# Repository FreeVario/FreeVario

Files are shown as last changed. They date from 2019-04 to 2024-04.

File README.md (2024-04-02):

# FreeVario
Freevario is an opensource vario that provides telemetry data to any vario based program such as XCSoar or XCTrack via bluetooth or USB in the form of NMEA sentences. It's a custom build pcb board* featuring:
 <br>
  STM32F405 processor  <br>
  E-Ink display  <br>
  GNSS module <br>
  BMP280 presure sensor <br>
  mpu6050 motion sensor <br>
  HM13 bluetooth module <br>
  SX1276 Lora Modem (for FANET) <br>
  Micro SDcard reader <br>
  Piezo buzzer output <br>
  USB-C connector for OTG and charging <br>  
  SWDIO port
  Signal LED
  CN3055 LiPo charger  
<br>
*The board is development status and there are some errors, don't use it for production or anything

The firmware runs on FreeRtos and STM32 HAL drivers. 

A lot of firmware features still have to be added and developed, but the milestone releases are practically usable

<br>
<br>
<center>
  <p > 
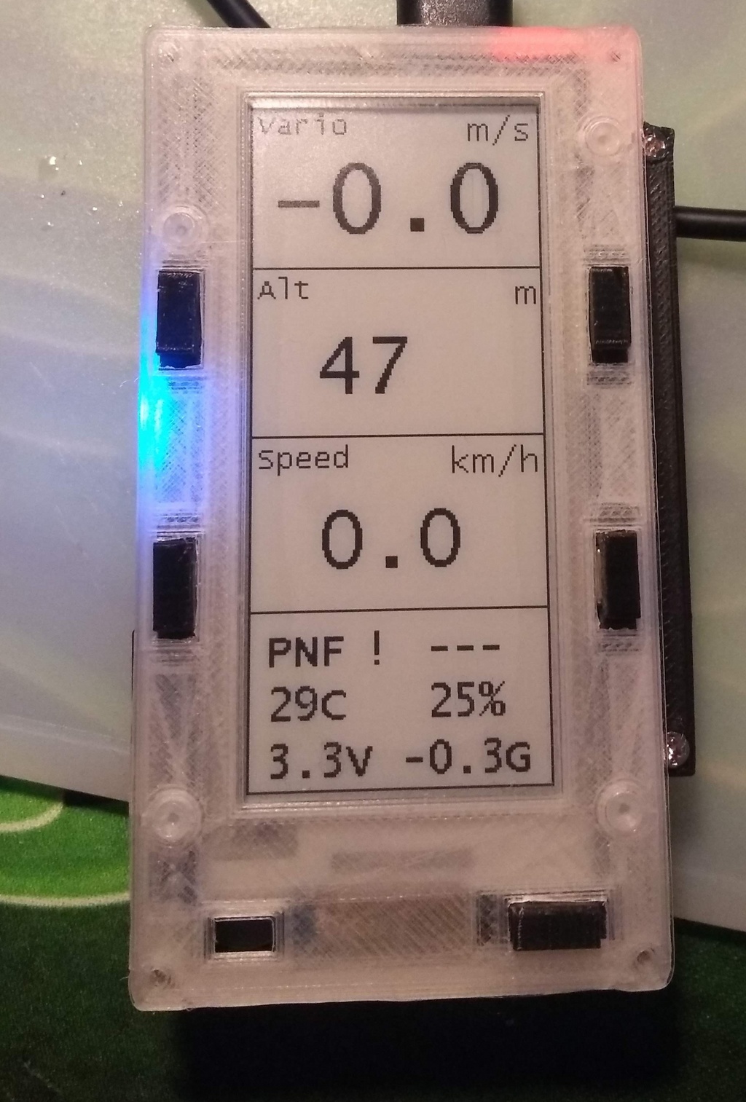
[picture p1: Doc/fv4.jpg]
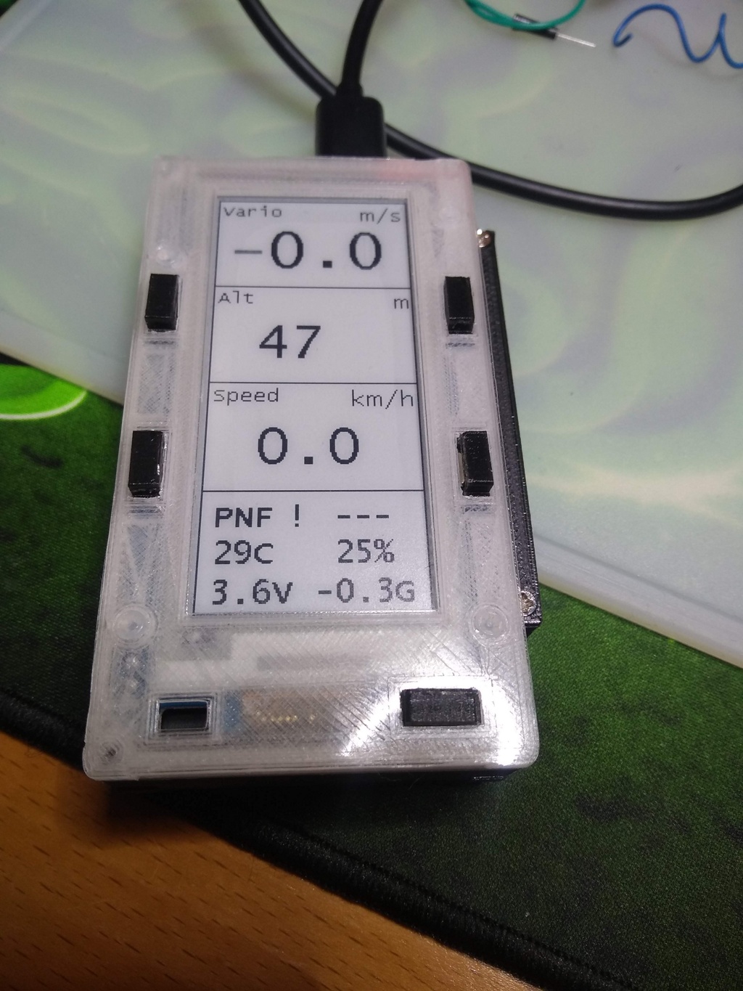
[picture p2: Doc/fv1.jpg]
     
  </p>
  
  <p > 
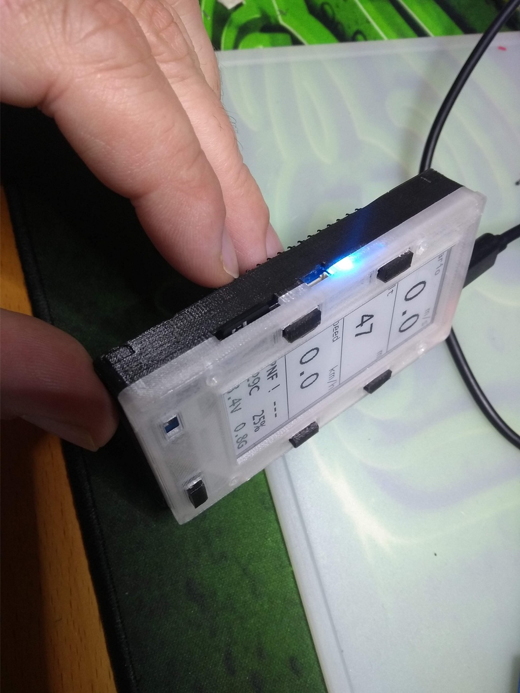
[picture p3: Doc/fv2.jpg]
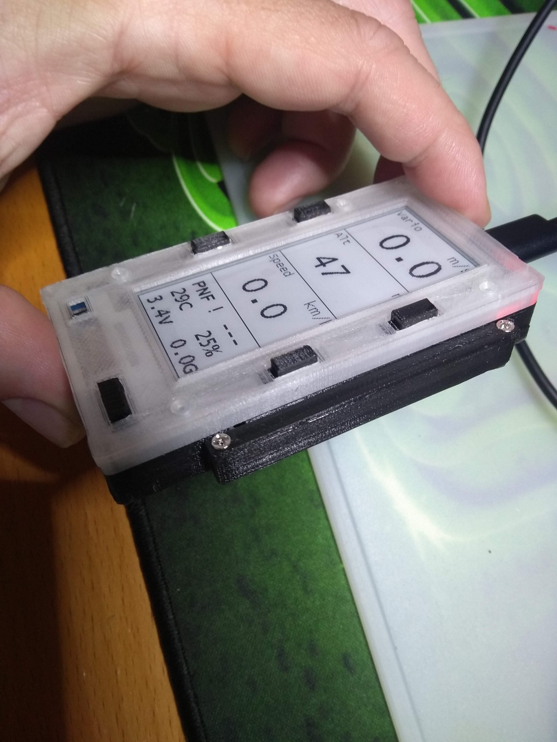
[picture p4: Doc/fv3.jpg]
     
  </p>
    <p > 
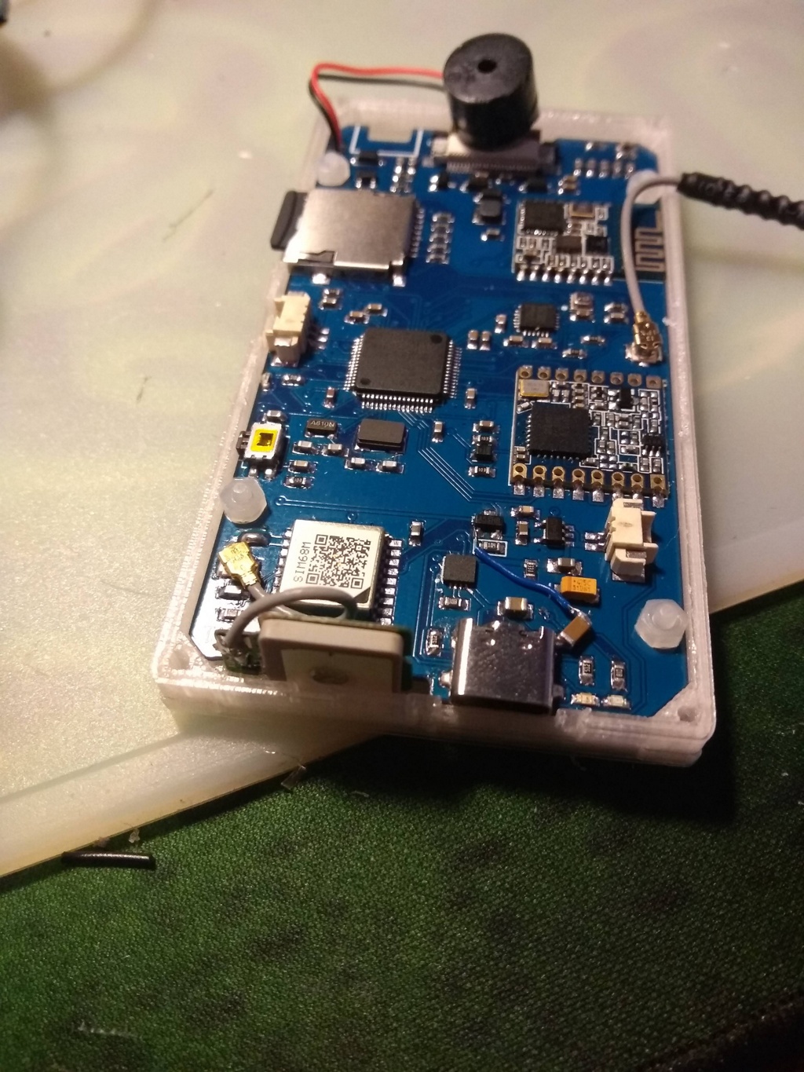
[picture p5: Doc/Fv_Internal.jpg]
    
  </p>
</center>

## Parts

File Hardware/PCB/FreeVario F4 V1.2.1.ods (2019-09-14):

Qty | Value | Device | Parts | Description
16 | 104 | C-EUC0603K | C3, C4, C22, C31, C32, C34, C35, C36, C37, C38, C39, C40, C41, C42, C43, C44 | CAPACITOR, European symbol
12 | 105 | C-EUC0603K | C2, C9, C10, C13, C15, C16, C19, C20, C23, C24, C25, C33 | CAPACITOR, European symbol
1 | 106 | C-EUC0603K | C12 | CAPACITOR, European symbol
1 | 223 | C-EUC0603K | C11 | CAPACITOR, European symbol
1 | 330 | R-EU_R0603 | R1 | RESISTOR, European symbol
1 | 0R | R-EU_R0603 | R9 | RESISTOR, European symbol
9 | 10k | R-EU_R0603 | R3, R6, R12, R13, R19, R21, R25, R26, R27 | RESISTOR, European symbol
1 | 10k | RES-0603 | R24
2 | 10p | C-EUC0603K | C5, C6 | CAPACITOR, European symbol
1 | 10R | R-EU_R0603 | R8 | RESISTOR, European symbol
1 | 10uF | C-EUC0603K | C21 | CAPACITOR, European symbol
1 | 10uF | C-EUC0805 | C18 | CAPACITOR, European symbol
2 | 1k | R-EU_R0603 | R7, R23 | RESISTOR, European symbol
1 | 1k | R-EU_R0603 | R2 | RESISTOR, European symbol
1 | 1N4148WS | DIODE-SOD323-R | D4 | DIODE
1 | 2.2nf | C-EUC0603K | C14 | CAPACITOR, European symbol
2 | 20p | C-EUC0603K | C7, C8 | CAPACITOR, European symbol
1 | 22uF | C-EUC0805 | C17 | CAPACITOR, European symbol
1 | 25MHZ | KX-9B | Y1 | Quartz Crystals (MHz) SMD:
1 | 27nH | INDUCTOR_0603_M | U$27 | Generic chip inductor
1 | 2k | R-EU_R0603 | R22 | RESISTOR, European symbol
1 | 2N7002 | MOSFET-NREFLOW | Q1 | N-Channel Mosfet
1 | 3R | R-EU_R0603 | R4 | RESISTOR, European symbol
1 | 4.7uF | 10UF-POLAR-EIA3216-16V-10%(TANT) | C1 | 10.0µF polarized capacitors
1 | 4.7uf | C-EUC0603K | C45 | CAPACITOR, European symbol
6 | 47k | R-EU_R0603 | R5, R11, R14, R15, R16, R20 | RESISTOR, European symbol
2 | 5.1k | R-EU_R0603 | R17, R18 | RESISTOR, European symbol
1 | 52745-2490 | 52745-2490 | X1 | FFC/FPC-to-Board 0.50mm (.020") SMT Top Contact
1 | 53261-02 | 53261-02 | BAT | CONNECTOR
1 | 53261-03 | 53261-03 | X3 | CONNECTOR
1 | 68uH | SWPA3015S2R2NT | L1 | Wire Wound SMD Power Inductor
1 | BME280 | BME280 | U1 | BME280 - Environmental Sensor (I2C + SPI)
1 | Cancel | MOMENTARY-SWITCH-SPST-SMD-6.0X3.5MM | S3 | Momentary Switch (Pushbutton) - SPST
1 | CN3065 | PMIC-CN3065-DFN8 | U3 | 310030101
1 | FC-135_32.7680KA-A0 | FC-135_32.7680KA-A0 | Y2 | None
1 | FDN340P | MOSFET-P'SI2323CDS/SI2305DS<BR>' | Q2 | 32.7680 Khz 20ppm 12.5pf
1 | GREEN | LEDCHIPLED_0603 | LED2 | LED
1 | HM-11 | HM-11 | HM13 | JNHuaMao HM-11 Bluetooth 4.0 Transceiver
4 | MBR0530 | DIODESOD-123 | D1, D2, D3, D5 | Diode
1 | MODULESX1276 | MODULESX1276 | U$4 | Module SX1276 LORA modem
1 | MPU-6050-1 | MPU-6050-1 | AC1
1 | Next | MOMENTARY-SWITCH-SPST-SMD-6.0X3.5MM | S4 | Momentary Switch (Pushbutton) - SPST
1 | OK | MOMENTARY-SWITCH-SPST-SMD-6.0X3.5MM | S5 | Momentary Switch (Pushbutton) - SPST
1 | Prev | MOMENTARY-SWITCH-SPST-SMD-6.0X3.5MM | S2 | Momentary Switch (Pushbutton) - SPST
1 | PWR | MOMENTARY-SWITCH-SPST-SMD-6.0X3.5MM | S1 | Momentary Switch (Pushbutton) - SPST
1 | RED | LEDCHIPLED_0603 | LED1 | LED
1 | RT9193-33 | MIC5219XX | REG1 | VOLTAGE REGULATOR
1 | s8050 | SMD-TRANSISTORS-PNP-25V-500MA(SOT-23) | T1 | 305020006
1 | SIM68M | SIM68M | U4
1 | STM32F405RGT6 | STM32F405RG | U$1 | STM32F405RGT6
1 | TF-HOLDER | TF-HOLDER | SD1 | TF / Micro SD socket is PUSH-PUSH type, the card can be pushed into and auto locked and pushed out by simply press the card.
2 | U.FL-R-SMT(01) | U.FL-R-SMT(01) | J1, J3 | U.FL Series 6 Ghz 50 Ohm Ultra-small SMT Coaxial Cable Receptacle
1 | USB-C_LOWSPEED | USB-C_LOWSPEED | U$2 | USB C Female connctor. Only uses the USB 2.0 data ports
1 |  | CONN_021X02_NO_SILK | J2 | Multi connection point. Often used as Generic Header-pin footprint for 0.1 inch spaced/style header connections
1 |  | LEDCHIP-LED0603 | LED3 | LED
1 |  | TS-015A | RESET | TS-15A

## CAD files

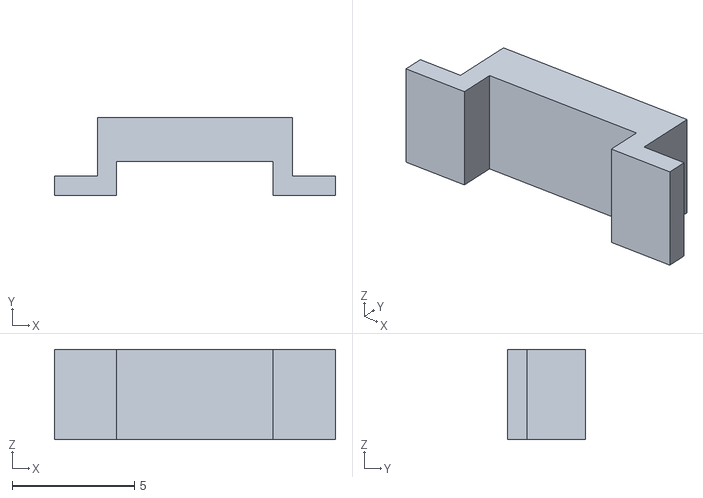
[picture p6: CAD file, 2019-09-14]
Hardware/Case/FreeVario F4 button.stl
11.5 x 3.20 x 3.70

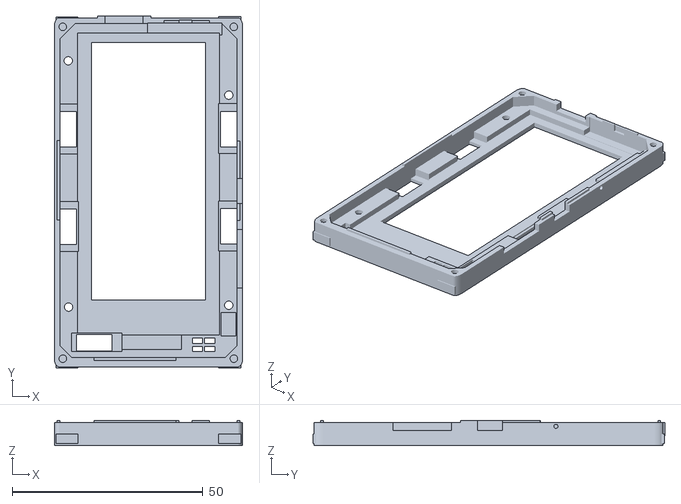
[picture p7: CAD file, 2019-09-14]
Hardware/Case/FreeVario F4 top.stl
49.4 x 92.3 x 6.60

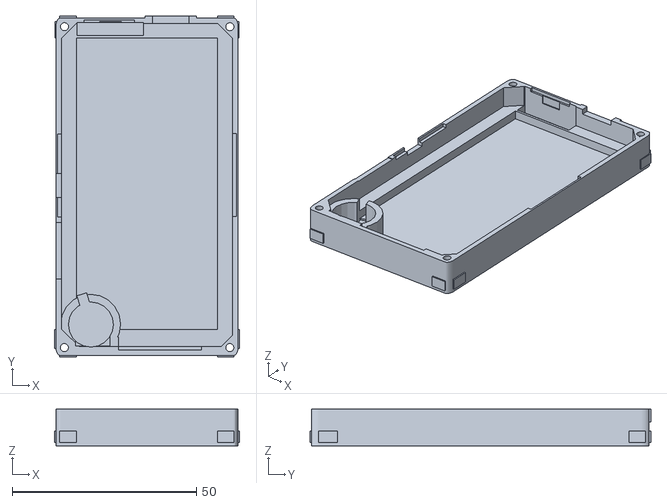
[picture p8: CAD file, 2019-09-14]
Hardware/Case/FreeVario F4 bottom.stl
50.2 x 92.5 x 10.0

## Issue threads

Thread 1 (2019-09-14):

Pcb design

Roeland54, 2019-09-14:
Hello,

I was in the starting phase of my own open source paragliding vario project with an e-paper display when I found your repository. It seems like the goals I had set for my project are more than fulfilled by yours.
I would love to make a FreeVario and maybe contribute to your project. I have the following questions:

- Can you add the pcb designs and maybe a bill of materials to the repository so I can start to build a FreeVario?
- Can you add The STL files for the 3d printed case to the repository.
- Do you plan on further developing the project?

primaldev, 2019-09-14:
Hi Roeland, thanks for your interest. I've added the files to the repository. You can use the eagle files if you need to modify the design, otherwise use the already prepared gerber files. All the parts is available from your nearest Chinese webshop (I kind of designed it for that).

At the moment it is still flying season so not much is done at the moment. I might pick it up again in the winter.

I had some bad luck with the pcb. I ordered a pcb with 1mm thickness and it turned out not being able to dissipate the heat of the charging chip properly and ended up tearing loose from the board. So advise at the moment is to use a thicker pcb.

Roeland54, 2020-02-22:
Hi, I finally picked this back up. Pcb and parts are ordered. Can you share the CAD files for the case? I may need to do some adjustments to the case to accommodate the thicker pcb. I also made the traces between the GND pad of the charging chip and the ground plane wider to improve thermal conductivity.

primaldev, 2020-02-22:
I sent you an email with a link to the project files on tinkercad.

thechillicherry, 2021-01-03:
Hey primaldev,
did you allready try the device? I found it like roeland54 i was looking for a vario which works with xctrack.
can you tell me where you ordered the components?
cheers thechillicherry

primaldev, 2021-01-03:
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

Hi, thanks for your interest, yes, I stil use it time to time, but have switched to another device (Mipfly). All the components should still be available from aliexpress. But keep in mind, this project requires a lot of skill and time and patience. This project had a smooth start, but I had a lot of last minute problems and just ran out of time for the season start and had to buy a commercial vario. You should be familiar with STM32 processors and coding, otherwise troubleshooting will be very difficult. Also, the LoRa should be left out. Turns out it was wired the wrong way around (Datasheet were incorrect/unclear).

A lot have changed the last few years with a lot of new players and projects on the market. Maybe, first have a look at [https://www.paraglidingforum.com/viewforum.php?f=39](url) for other options.

But if you are up for the challenge, I suggest contacting Roeland as well, he did some improvements on the PCB.

ra1amx, 2023-06-10:
Hi. You can add a BOM file and a component coordinate file to order a board on a production type jlcpcb.com
Thanks!

Closed 2024-07-13.

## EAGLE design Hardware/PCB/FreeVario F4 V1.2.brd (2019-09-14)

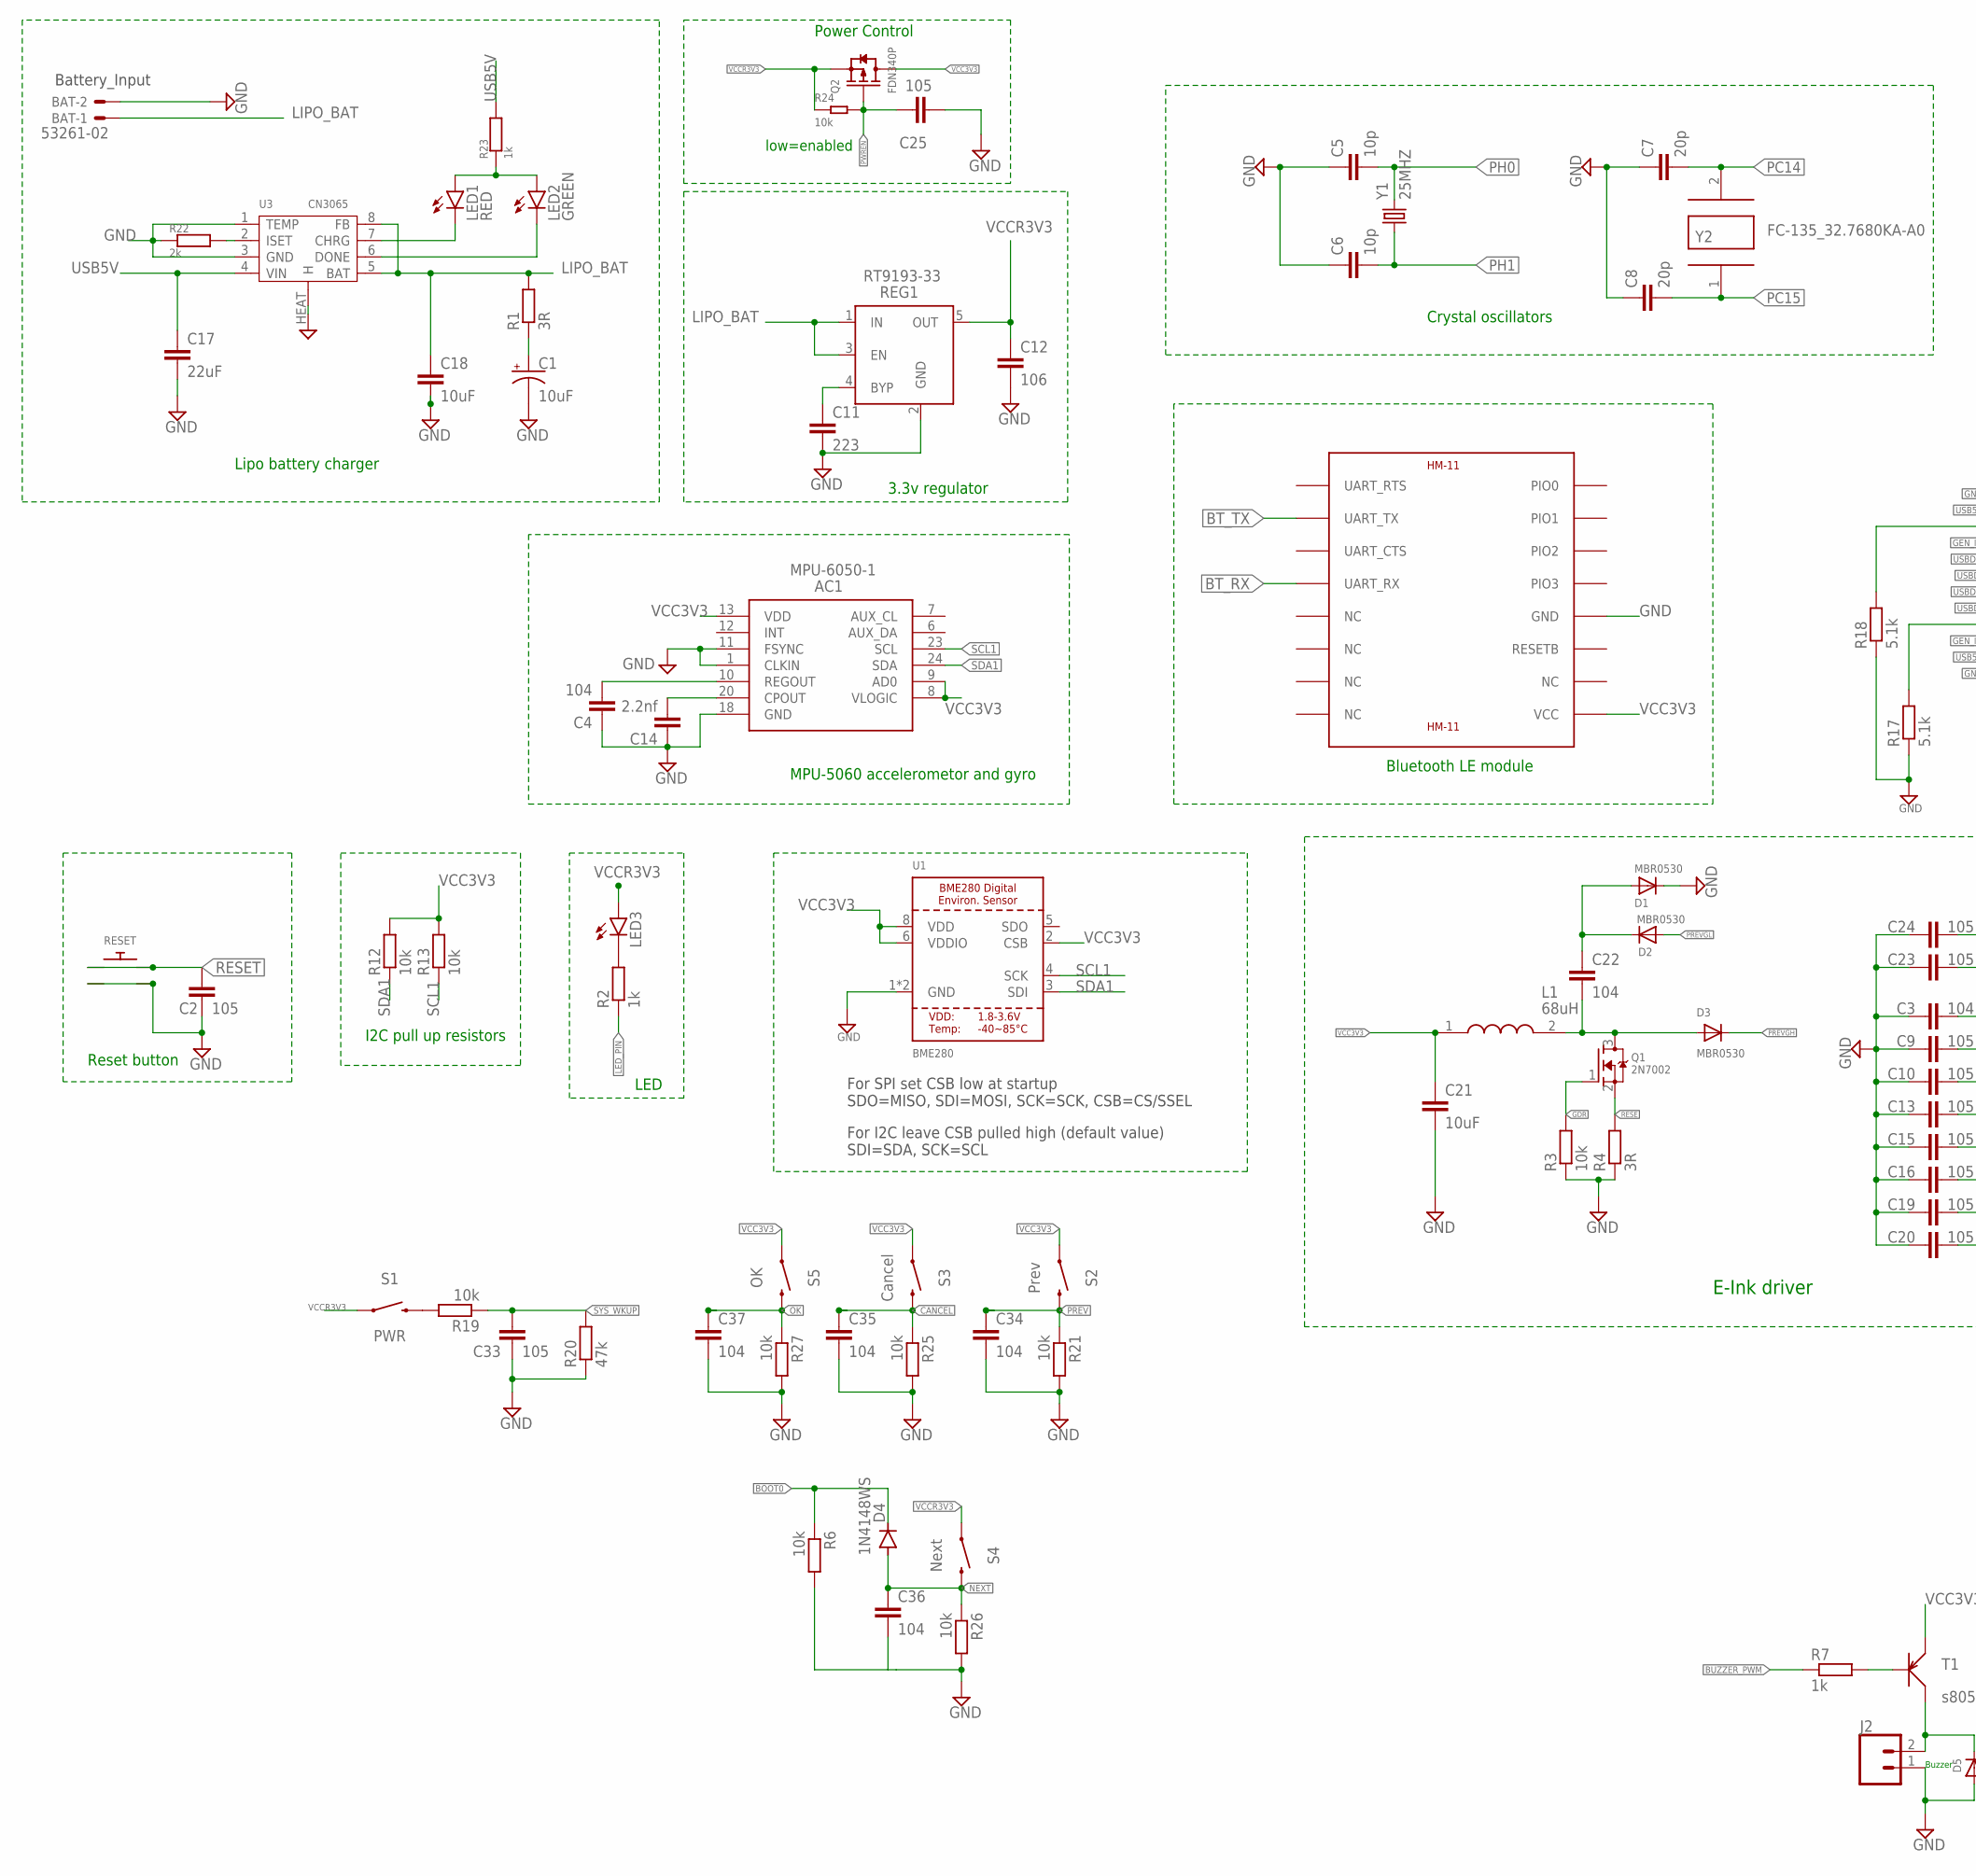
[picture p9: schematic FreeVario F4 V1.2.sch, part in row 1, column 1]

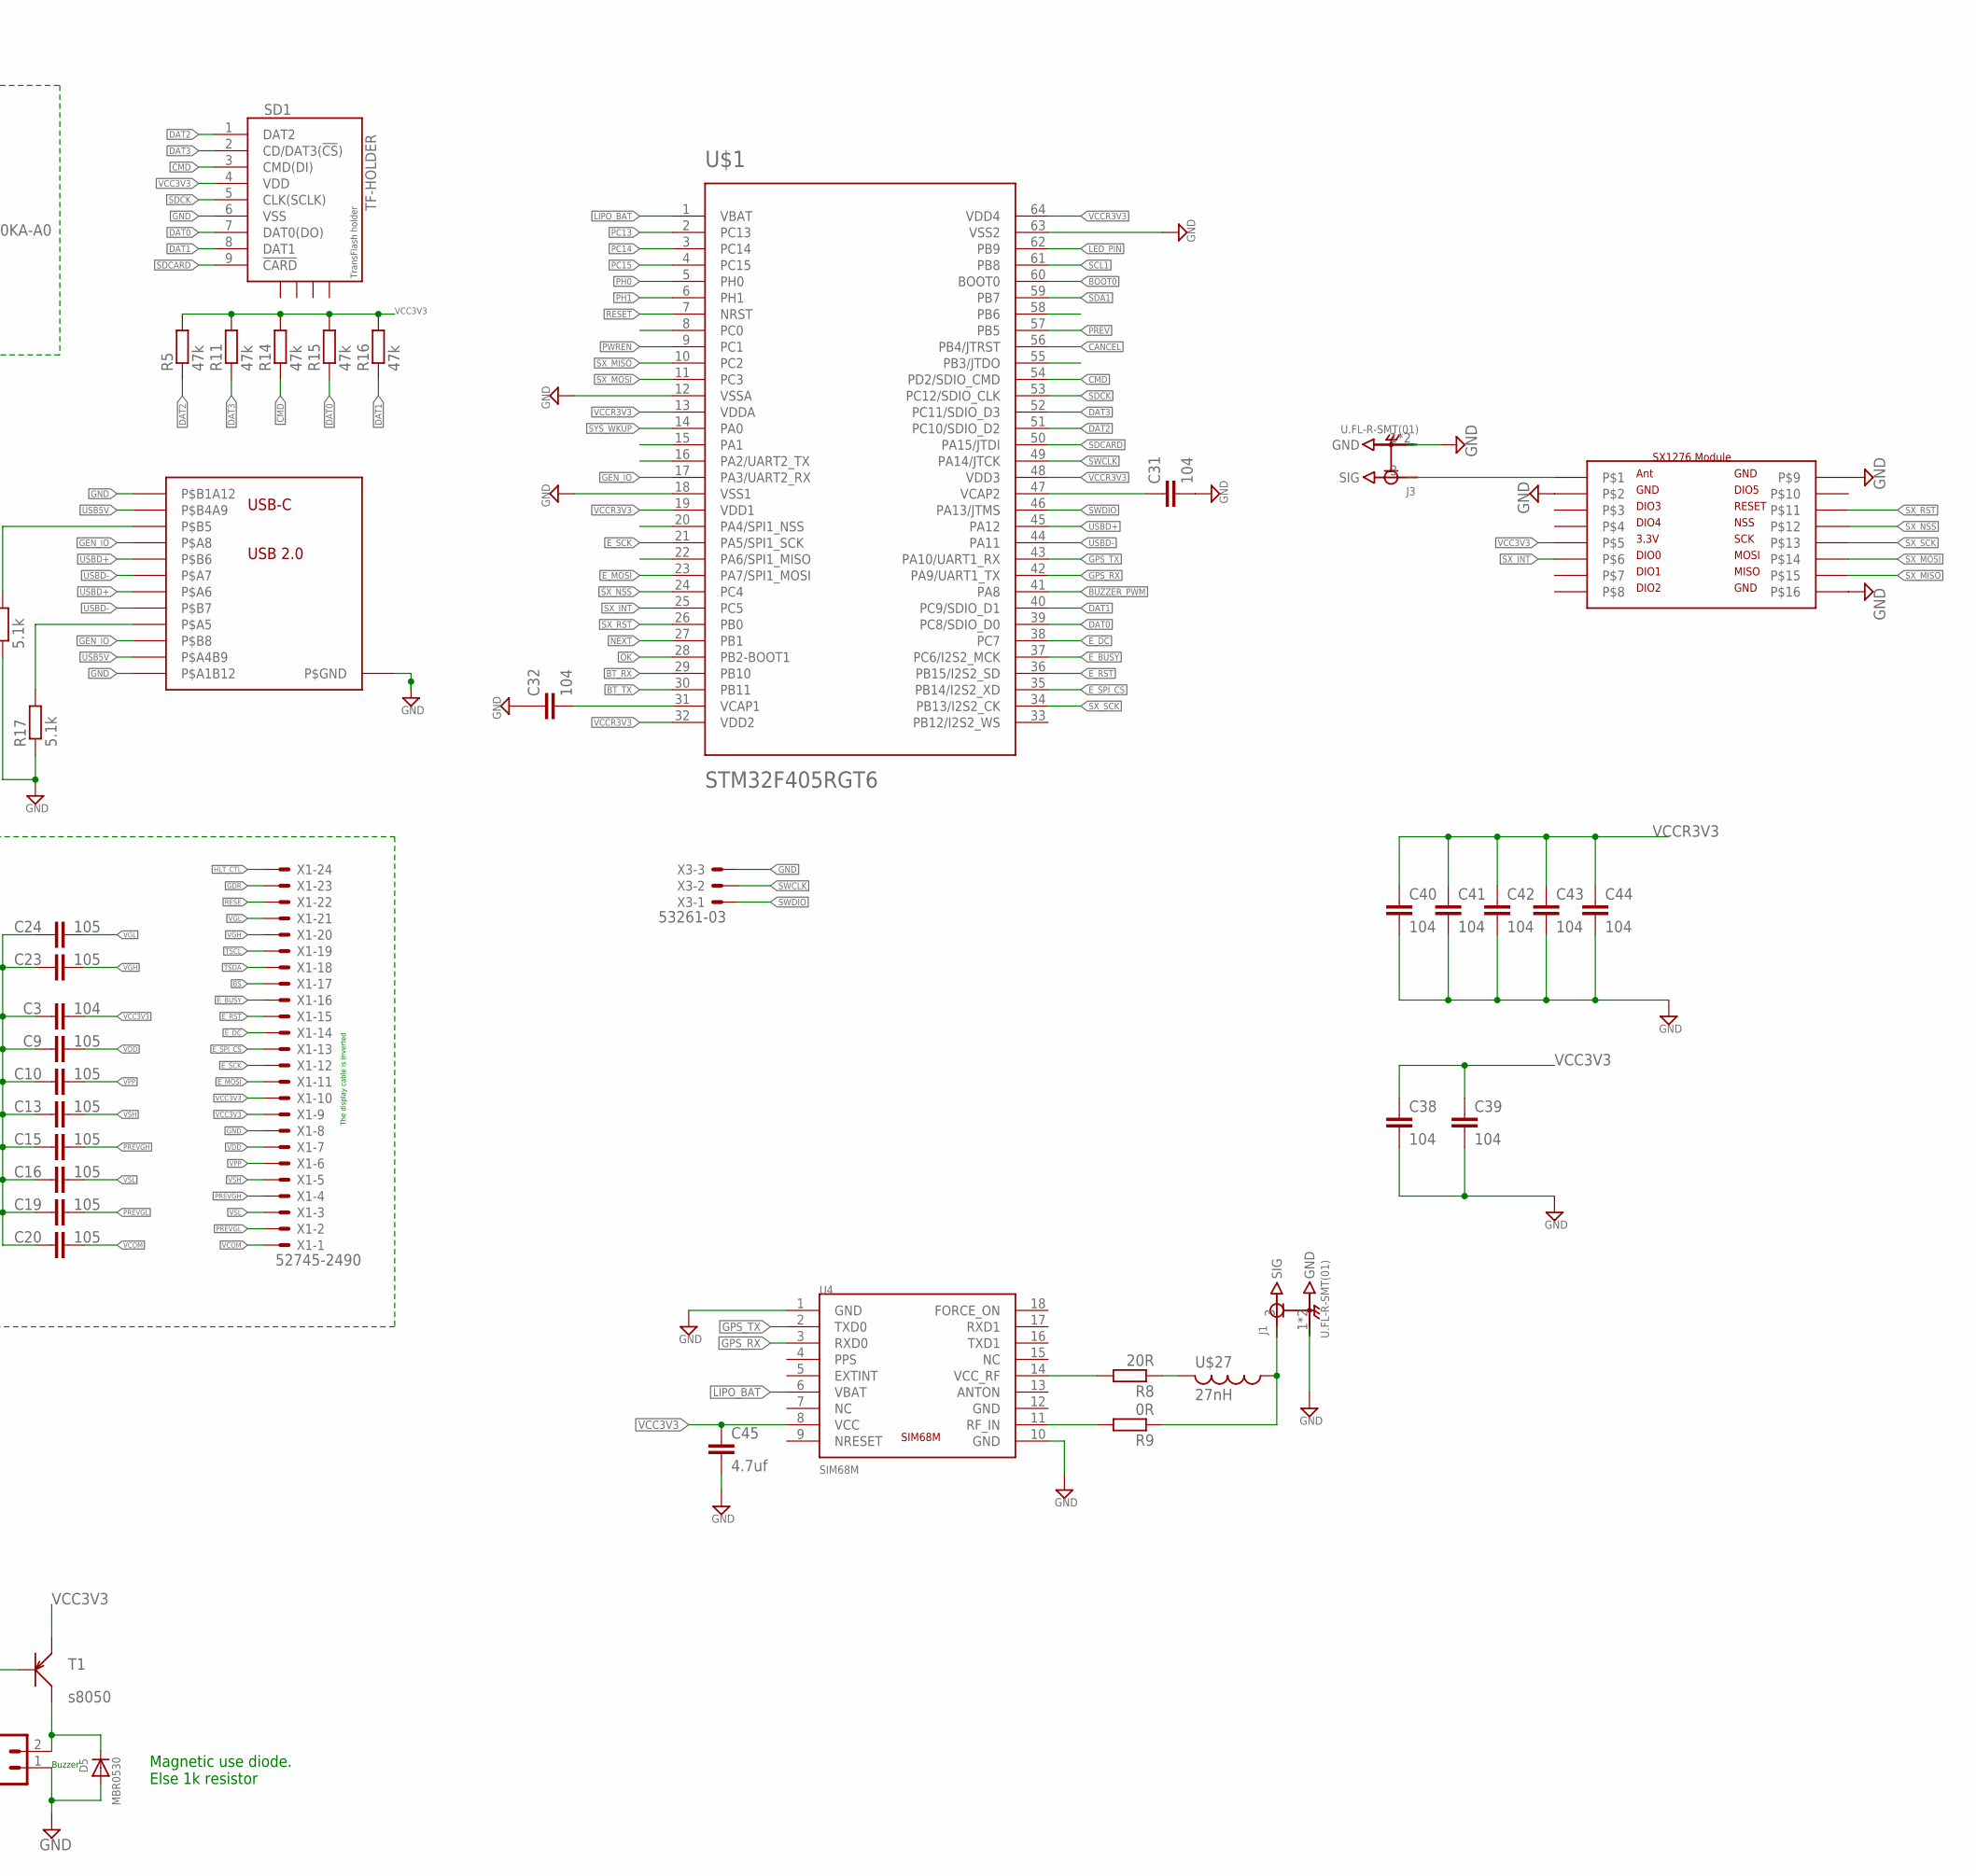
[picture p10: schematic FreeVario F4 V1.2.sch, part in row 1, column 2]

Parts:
AC1: MPU-6050-1; QFN-24-4MM2
BAT: 53261-02
C1: 10uF; EIA3216
C2, C9, C10, C13, C15, C16, C19, C20, C23, C24, C25, C33: 105; C0603K
C3, C4, C22, C31, C32, C34, C35, C36, C37, C38, C39, C40, C41, C42, C43, C44: 104; C0603K
C5, C6: 10p; C0603K
C7, C8: 20p; C0603K
C11: 223; C0603K
C12: 106; C0603K
C14: 2.2nf; C0603K
C17: 22uF; C0805
C18: 10uF; C0805
C21: 10uF; C0603K
C45: 4.7uf; C0603K
D1, D2, D3, D5: MBR0530; SOD-123
D4: 1N4148WS; SOD323-R
HM13: HM-11
J1, J3: U.FL-R-SMT(01); HRS_U.FL-R-SMT(01)
J2: CONN_021X02_NO_SILK; 1X02_NO_SILK
L1: 68uH; INDPM3030X150N
LED1: RED; CHIPLED_0603
LED2: GREEN; CHIPLED_0603
LED3: LEDCHIP-LED0603; CHIP-LED0603
Q1: 2N7002; SOT23
Q2: FDN340P; SOT-23
R1, R4: 3R; R0603
R2, R7, R23: 1k; R0603
R3, R6, R12, R13, R19, R21, R24, R25, R26, R27: 10k; R0603
R5, R11, R14, R15, R16, R20: 47k; R0603
R8: 20R; R0603
R9: 0R; R0603
R17, R18: 5.1k; R0603
R22: 2k; R0603
REG1: RT9193-33; SOT23-5
RESET: TS-015A
S1: PWR; TACTILE_SWITCH_SMD_6.0X3.5MM
S2: Prev; TACTILE_SWITCH_SMD_6.0X3.5MM
S3: Cancel; TACTILE_SWITCH_SMD_6.0X3.5MM
S4: Next; TACTILE_SWITCH_SMD_6.0X3.5MM
S5: OK; TACTILE_SWITCH_SMD_6.0X3.5MM
SD1: TF-HOLDER; TF-PULL
T1: s8050; SOT-23
U1: BME280
U3: CN3065; DFN-8
U4: SIM68M
U$1: STM32F405RGT6; TQFP64
U$2: USB-C_LOWSPEED
U$4: MODULESX1276
U$27: 27nH; RESC0603_M
X1: 52745-2490
X3: 53261-03
Y1: 25MHZ; 5.0X3.2_2
Y2: FC-135_32.7680KA-A0; XTAL_FC-135_32.7680KA-A0

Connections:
BOOT0: D4.C, R6.1, U$1.60 (BOOT0)
BS: X1.17
BT_RX: HM13.UART_RX, U$1.29 (PB10)
BT_TX: HM13.UART_TX, U$1.30 (PB11)
BUZZER_PWM: R7.1, U$1.41 (PA8)
CANCEL: C35.1, R25.1, S3.2, U$1.56 (PB4/JTRST)
CMD: R14.1, SD1.3 (CMD(DI)), U$1.54 (PD2/SDIO_CMD)
DAT0: R15.1, SD1.7 (DAT0(DO)), U$1.39 (PC8/SDIO_D0)
DAT1: R16.1, SD1.8 (DAT1), U$1.40 (PC9/SDIO_D1)
DAT2: R5.1, SD1.1 (DAT2), U$1.51 (PC10/SDIO_D2)
DAT3: R11.1, SD1.2 (CD/DAT3(!CS!)), U$1.52 (PC11/SDIO_D3)
E_BUSY: U$1.37 (PC6/I2S2_MCK), X1.16
E_DC: U$1.38 (PC7), X1.14
E_MOSI: U$1.23 (PA7/SPI1_MOSI), X1.11
E_RST: U$1.36 (PB15/I2S2_SD), X1.15
E_SCK: U$1.21 (PA5/SPI1_SCK), X1.12
E_SPI_CS: U$1.35 (PB14/I2S2_XD), X1.13
GDR: Q1.1 (G), R3.2, X1.23
GEN_IO: U$1.17 (PA3/UART2_RX), U$2.P$A8, U$2.P$B8
GND: AC1.1 (CLKIN), AC1.11 (FSYNC), AC1.18 (GND), BAT.2, C1.-, C2.2, C3.1, C4.1, C5.1, C6.1, C7.1, C8.1, C9.1, C10.1, C11.2, C12.2, C13.1, C14.1, C15.1, C16.1, C17.2, C18.2, C19.1, C20.1, C21.2, C23.1, C24.1, C25.2, C31.2, C32.1, C33.2, C34.2, C35.2, C36.2, C37.2, C38.2, C39.2, C40.2, C41.2, C42.2, C43.2, C44.2, C45.2, D1.C, D5.A, HM13.GND, J1.1 (GND), J1.2 (GND), J2.1, J3.1 (GND), J3.2 (GND), R3.1, R4.1, R6.2, R17.1, R18.1, R20.1, R21.2, R22.1, R25.2, R26.2, R27.2, REG1.2 (GND), RESET.P$2, RESET.P$4, SD1.6 (VSS), U1.1 (GND), U1.7 (GND), U3.1 (TEMP), U3.3 (GND), U3.HEAT (H), U4.1 (GND), U4.10 (GND), U4.12 (GND), U$1.12 (VSSA), U$1.18 (VSS1), U$1.63 (VSS2), U$2.P$1 (P$GND), U$2.P$2 (P$GND), U$2.P$20 (P$GND), U$2.P$21 (P$GND), U$2.P$22 (P$GND), U$2.P$23 (P$GND), U$2.P$A1B12, U$2.P$B1A12, U$4.SX2, U$4.SX9, U$4.SX16, X1.8, X3.3
GPS_RX: U4.3 (RXD0), U$1.42 (PA9/UART1_TX)
GPS_TX: U4.2 (TXD0), U$1.43 (PA10/UART1_RX)
HLT_CTL: X1.24
LED_PIN: R2.1, U$1.62 (PB9)
LIPO_BAT: BAT.1, C18.1, R1.2, REG1.1 (IN), REG1.3 (EN), U3.5 (BAT), U3.8 (FB), U4.6 (VBAT), U$1.1 (VBAT)
unnamed: LED1.A, LED2.A, R23.1
unnamed: LED1.C, U3.7 (CHRG)
unnamed: LED2.C, U3.6 (DONE)
unnamed: C1.+, R1.1
unnamed: C11.1, REG1.4 (BYP)
unnamed: J1.3 (SIG), R9.1, U$27.1
unnamed: LED3.C, R2.2
unnamed: C22.2, D3.A, L1.2, Q1.3 (D)
unnamed: R19.2, S1.2
unnamed: R8.1, U$27.2
unnamed: C22.1, D1.A, D2.C
unnamed: J3.3 (SIG), U$4.SX1
unnamed: D5.C, J2.2, T1.3 (C)
unnamed: R7.2, T1.1 (B)
unnamed: AC1.10 (REGOUT), C4.2
unnamed: R8.2, U4.14 (VCC_RF)
unnamed: R22.2, U3.2 (ISET)
unnamed: AC1.20 (CPOUT), C14.2
unnamed: R9.2, U4.11 (RF_IN)
unnamed: C32.2, U$1.31 (VCAP1)
unnamed: C31.1, U$1.47 (VCAP2)
unnamed: R17.2, U$2.P$A5
unnamed: R18.2, U$2.P$B5
NEXT: C36.1, D4.A, R26.1, S4.2, U$1.27 (PB1)
OK: C37.1, R27.1, S5.2, U$1.28 (PB2-BOOT1)
PC0: U$1.8 (PC0)
PC13: U$1.2 (PC13)
PC14: C7.2, U$1.3 (PC14), Y2.2
PC15: C8.2, U$1.4 (PC15), Y2.1
PH0: C5.2, U$1.5 (PH0), Y1.2
PH1: C6.2, U$1.6 (PH1), Y1.1
PREV: C34.1, R21.1, S2.2, U$1.57 (PB5)
PREVGH: C15.2, D3.C, X1.4
PREVGL: C19.2, D2.A, X1.2
PWREN: C25.1, Q2.1 (G), R24.2, U$1.9 (PC1)
RESE: Q1.2 (S), R4.2, X1.22
RESET: C2.1, RESET.P$1, RESET.P$3, U$1.7 (NRST)
SCL1: AC1.23 (SCL), R13.1, U1.4 (SCK), U$1.61 (PB8)
SDA1: AC1.24 (SDA), R12.1, U1.3 (SDI), U$1.59 (PB7)
SDCARD: SD1.9 (!CARD), U$1.50 (PA15/JTDI)
SDCK: SD1.5 (CLK(SCLK)), U$1.53 (PC12/SDIO_CLK)
SWCLK: U$1.49 (PA14/JTCK), X3.2
SWDIO: U$1.46 (PA13/JTMS), X3.1
SX_INT: U$1.25 (PC5), U$4.SX6
SX_MISO: U$1.10 (PC2), U$4.SX15
SX_MOSI: U$1.11 (PC3), U$4.SX14
SX_NSS: U$1.24 (PC4), U$4.SX12
SX_RST: U$1.26 (PB0), U$4.SX11
SX_SCK: U$1.34 (PB13/I2S2_CK), U$4.SX13
SYS_WKUP: C33.1, R19.1, R20.2, U$1.14 (PA0)
TSCL: X1.19
TSDA: X1.18
USB5V: C17.1, R23.2, U3.4 (VIN), U$2.P$A4B9, U$2.P$B4A9
USBD+: U$1.45 (PA12), U$2.P$A6, U$2.P$B6
USBD-: U$1.44 (PA11), U$2.P$A7, U$2.P$B7
VCC3V3: AC1.8 (VLOGIC), AC1.9 (AD0), AC1.13 (VDD), C3.2, C21.1, C38.1, C39.1, C45.1, HM13.VCC, L1.1, Q2.3 (D), R5.2, R11.2, R12.2, R13.2, R14.2, R15.2, R16.2, S2.1, S3.1, S5.1, SD1.4 (VDD), T1.2 (E), U1.2 (CSB), U1.6 (VDDIO), U1.8 (VDD), U4.8 (VCC), U$4.SX5, X1.9, X1.10
VCCR3V3: C12.1, C40.1, C41.1, C42.1, C43.1, C44.1, LED3.A, Q2.2 (S), R24.1, REG1.5 (OUT), S1.1, S4.1, U$1.13 (VDDA), U$1.19 (VDD1), U$1.32 (VDD2), U$1.48 (VDD3), U$1.64 (VDD4)
VCOM: C20.2, X1.1
VDD: C9.2, X1.7
VGH: C23.2, X1.20
VGL: C24.2, X1.21
VPP: C10.2, X1.6
VSH: C13.2, X1.5
VSL: C16.2, X1.3

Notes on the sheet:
Battery_Input
Lipo battery charger
Bluetooth LE module
MPU-5060 accelerometor and gyro
3.3v regulator
Reset button
I2C pull up resistors
LED
For SPI set CSB low at startup SDO=MISO, SDI=MOSI, SCK=SCK, CSB=CS/SSEL
For I2C leave CSB pulled high (default value) SDI=SDA, SCK=SCL
Crystal oscillators
The display cable is inverted
Power Control
low=enabled
E-Ink driver
Buzzer
Magnetic use diode. Else 1k resistor

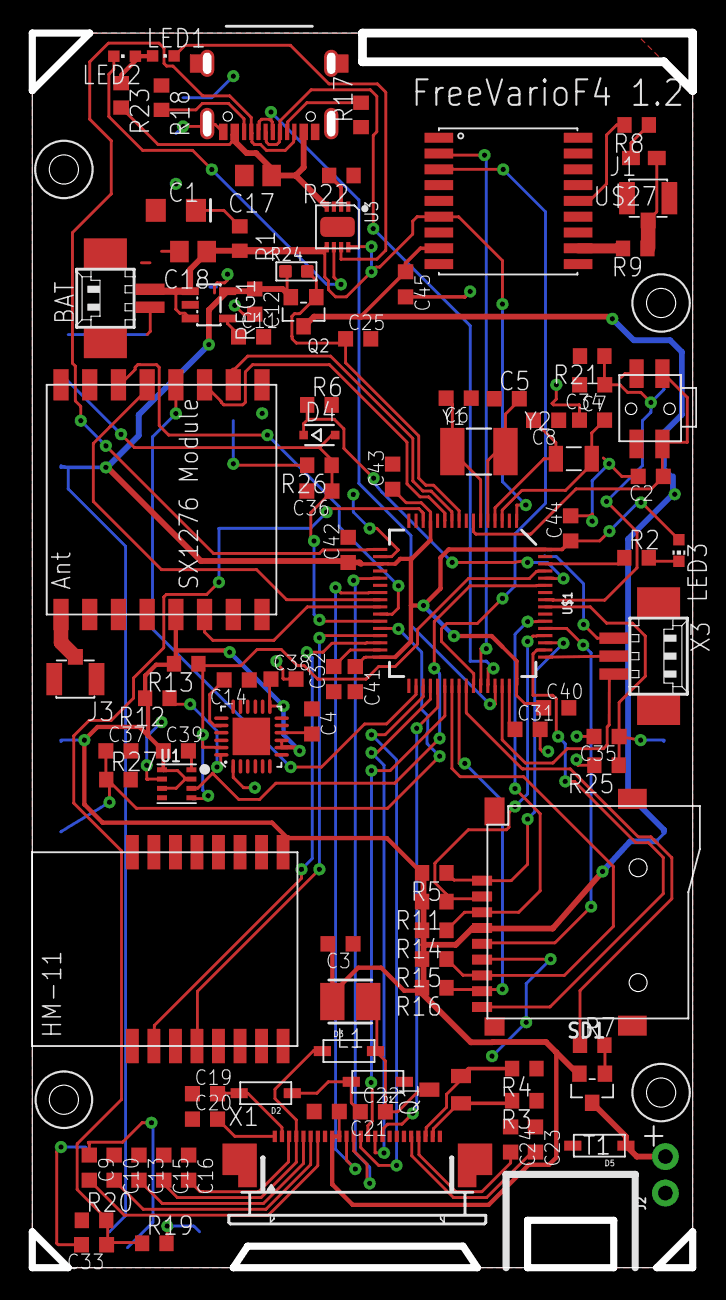
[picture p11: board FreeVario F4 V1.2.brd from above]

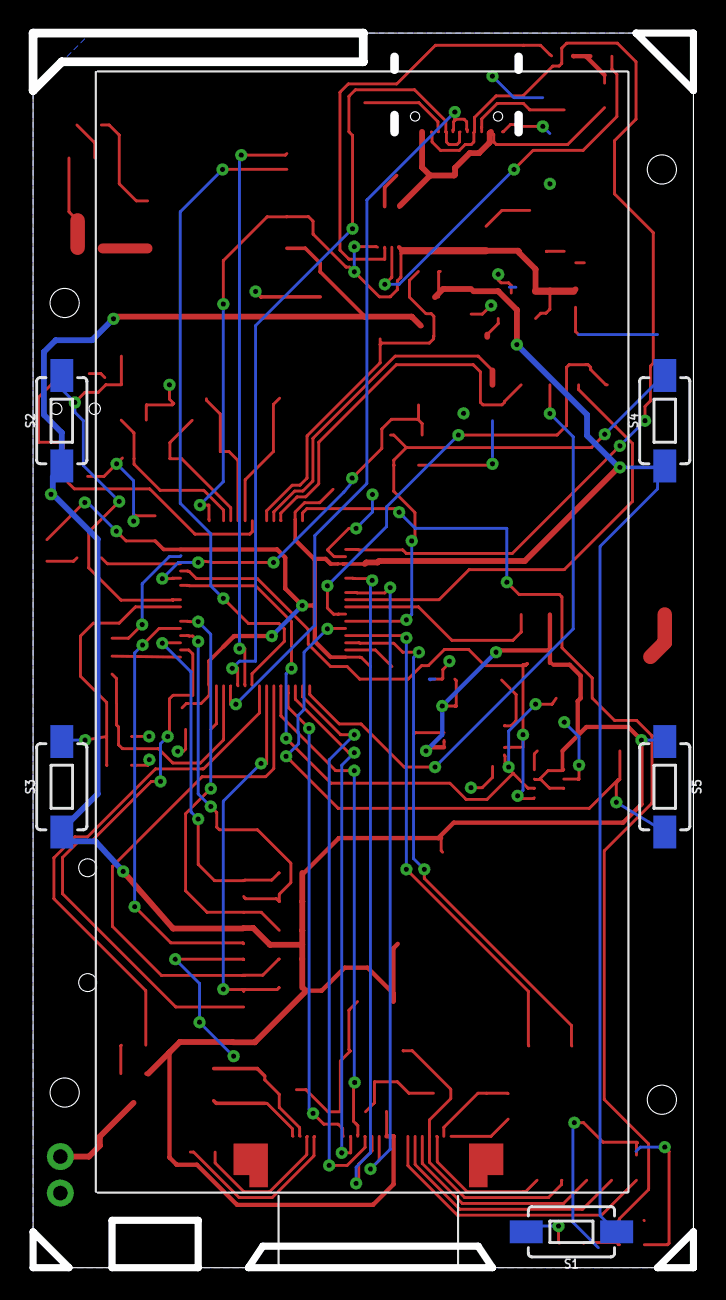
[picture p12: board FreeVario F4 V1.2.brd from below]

Board: 2 copper layers, 46.0 x 86.0 mm, 103 parts (5 on the bottom side), 83 nets.

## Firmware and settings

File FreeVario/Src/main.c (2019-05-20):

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

/* Includes ------------------------------------------------------------------*/
#include "main.h"
#include "cmsis_os.h"
#include "fatfs.h"
#include "usb_device.h"

/* USER CODE BEGIN Includes */
#include "freevario.h"
/* USER CODE END Includes */

ADC_HandleTypeDef hadc1;

I2C_HandleTypeDef hi2c1;

RTC_HandleTypeDef hrtc;

SD_HandleTypeDef hsd;
DMA_HandleTypeDef hdma_sdio_rx;
DMA_HandleTypeDef hdma_sdio_tx;

SPI_HandleTypeDef hspi1;
SPI_HandleTypeDef hspi2;

TIM_HandleTypeDef htim1;

UART_HandleTypeDef huart1;
UART_HandleTypeDef huart3;
DMA_HandleTypeDef hdma_usart1_rx;
DMA_HandleTypeDef hdma_usart3_tx;

WWDG_HandleTypeDef hwwdg;

osThreadId defaultTaskHandle;
/* USER CODE BEGIN PV */


/* USER CODE END PV */

void SystemClock_Config(void);
static void MX_GPIO_Init(void);
static void MX_DMA_Init(void);
static void MX_USART3_UART_Init(void);
static void MX_SPI1_Init(void);
static void MX_SPI2_Init(void);
static void MX_I2C1_Init(void);
static void MX_SDIO_SD_Init(void);
static void MX_USART1_UART_Init(void);
static void MX_TIM1_Init(void);
static void MX_RTC_Init(void);
static void MX_ADC1_Init(void);
static void MX_WWDG_Init(void);
void StartDefaultTask(void const * argument);

/* USER CODE BEGIN PFP */

/* USER CODE END PFP */

/**
  * @brief  The application entry point.
  * @retval int
  */
int main(void)
{
  /* MCU Configuration--------------------------------------------------------*/

  /* Reset of all peripherals, Initializes the Flash interface and the Systick. */
  HAL_Init();

  /* Configure the system clock */
  SystemClock_Config();

  /* USER CODE BEGIN SysInit */
//After using generate code in cubeMX, add this after GPIO_INIT :   HAL_Delay(100);


  MX_GPIO_Init();
  HAL_Delay(100);
  MX_DMA_Init();
  MX_USART3_UART_Init();
  MX_SPI1_Init();
  MX_SPI2_Init();
  MX_I2C1_Init();
  MX_SDIO_SD_Init();
  MX_USART1_UART_Init();
  MX_TIM1_Init();
  MX_RTC_Init();
  MX_ADC1_Init();


  /* USER CODE END SysInit */

  /* Initialize all configured peripherals */
  /* USER CODE BEGIN 2 */
#ifndef  DEBUG_MODE
  /*Disable RTC tamper*/

  HAL_RTCEx_DeactivateTamper(&hrtc, RTC_TAMPER_1);
  __HAL_RTC_TAMPER_CLEAR_FLAG(&hrtc, RTC_FLAG_TAMP1F);
  __HAL_RTC_WRITEPROTECTION_DISABLE(&hrtc);
  HAL_PWR_EnableBkUpAccess();

 /*
  * Bug fix for pwr button
  * Button must be held in for 3 seconds to powerup
  */

    uint32_t extRequest = HAL_RTCEx_BKUPRead(&hrtc, 0);

    /*check if the shutdown was proper */
    /*if not, continue startup in case of a wwdg reset*/
    if (extRequest == 3) { //had normal shutdown
        HAL_Delay(PWRBUTTONDELAY);
        if (HAL_GPIO_ReadPin(PWRBUTTON_GPIO_Port, PWRBUTTON_Pin)
                == GPIO_PIN_RESET) {
            StandbyMode();
        }

        /*Clear the proper shutdown flag */
        HAL_RTCEx_BKUPWrite(&hrtc, 0, 1); //do normal startup

    } else {
        HAL_RTCEx_BKUPWrite(&hrtc, 0, 2); //unexpected restart
    }

#endif

#ifndef  DEBUG_MODE
  MX_WWDG_Init();
#endif


//Support for previous model that uses NPN transistor for the buzzer
  //TODO: read cpu serial as a switch



#ifdef FV_NPN_CHECK


  if ((STM32_UUID[2]) == 825503794) { //Id of the 1 board that needs this

        //char buff[30];
        //sprintf(buff, "serial %d \r\n", idPart3);
        //CDC_Transmit_FS(buff, 30);

        TIM_OC_InitTypeDef sConfigOC = { 0 };
        sConfigOC.OCMode = TIM_OCMODE_PWM1;
        sConfigOC.Pulse = 0;
        sConfigOC.OCPolarity = TIM_OCPOLARITY_LOW;
        sConfigOC.OCNPolarity = TIM_OCNPOLARITY_LOW;
        sConfigOC.OCFastMode = TIM_OCFAST_DISABLE;
        sConfigOC.OCIdleState = TIM_OCIDLESTATE_RESET;
        sConfigOC.OCNIdleState = TIM_OCNIDLESTATE_RESET;
        if (HAL_TIM_PWM_ConfigChannel(&htim1, &sConfigOC, TIM_CHANNEL_1)
                != HAL_OK) {
            Error_Handler();
        }

    }

#endif
  /* USER CODE END 2 */

  /* USER CODE BEGIN RTOS_MUTEX */
  /* add mutexes, ... */
  /* USER CODE END RTOS_MUTEX */

  /* USER CODE BEGIN RTOS_SEMAPHORES */
  /* add semaphores, ... */
  /* USER CODE END RTOS_SEMAPHORES */

  /* USER CODE BEGIN RTOS_TIMERS */
  /* start timers, add new ones, ... */
  /* USER CODE END RTOS_TIMERS */

  /* Create the thread(s) */
  /* definition and creation of defaultTask */
  osThreadDef(defaultTask, StartDefaultTask, osPriorityNormal, 0, 1024);
  defaultTaskHandle = osThreadCreate(osThread(defaultTask), NULL);

  /* USER CODE BEGIN RTOS_THREADS */
  /* add threads, ... */

  freeVario_RTOS_Init();



  /* USER CODE END RTOS_THREADS */

  /* USER CODE BEGIN RTOS_QUEUES */
  /* add queues, ... */
  /* USER CODE END RTOS_QUEUES */
 

  /* Start scheduler */
  osKernelStart();
  
  /* We should never get here as control is now taken by the scheduler */

  /* Infinite loop */
  /* USER CODE BEGIN WHILE */
  while (1)
  {

    /* USER CODE END WHILE */

    /* USER CODE BEGIN 3 */

  }
  /* USER CODE END 3 */
}

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
/* USER CODE BEGIN Header_StartDefaultTask */
/**
  * @brief  Function implementing the defaultTask thread.
  * @param  argument: Not used 
  * @retval None
  */
/* USER CODE END Header_StartDefaultTask */
__weak void StartDefaultTask(void const * argument)
{

  /* USER CODE BEGIN 5 */
  /* Infinite loop */
  for(;;)
  {

    osDelay(1);
  }
  /* USER CODE END 5 */ 
}

/**
  * @brief  Period elapsed callback in non blocking mode
  * @note   This function is called  when TIM5 interrupt took place, inside
  * HAL_TIM_IRQHandler(). It makes a direct call to HAL_IncTick() to increment
  * a global variable "uwTick" used as application time base.
  * @param  htim : TIM handle
  * @retval None
  */
void HAL_TIM_PeriodElapsedCallback(TIM_HandleTypeDef *htim)
{
  if (htim->Instance == TIM5) {
    HAL_IncTick();
  }
}

/**
  * @brief  This function is executed in case of error occurrence.
  * @retval None
  */
void Error_Handler(void)
{
  /* USER CODE BEGIN Error_Handler_Debug */
  /* User can add his own implementation to report the HAL error return state */
  while(1)
  {
  }
  /* USER CODE END Error_Handler_Debug */
}

#ifdef  USE_FULL_ASSERT
/**
  * @brief  Reports the name of the source file and the source line number
  *         where the assert_param error has occurred.
  * @param  file: pointer to the source file name
  * @param  line: assert_param error line source number
  * @retval None
  */
void assert_failed(uint8_t *file, uint32_t line)
{ 
  /* USER CODE BEGIN 6 */
  /* User can add his own implementation to report the file name and line number,
     tex: printf("Wrong parameters value: file %s on line %d\r\n", file, line) */
  /* USER CODE END 6 */
}
#endif /* USE_FULL_ASSERT */

/************************ (C) COPYRIGHT STMicroelectronics *****END OF FILE****/

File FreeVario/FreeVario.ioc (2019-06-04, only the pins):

Mcu.UserName=STM32F405RGTx
PA0-WKUP.GPIO_Label=PWRBUTTON
PA0-WKUP.Signal=GPXTI0
PA10.GPIO_Label=GPS_USART_RX
PA10.Signal=USART1_RX
PA11.Signal=USB_OTG_FS_DM
PA12.Signal=USB_OTG_FS_DP
PA13.Signal=SYS_JTMS-SWDIO
PA14.Signal=SYS_JTCK-SWCLK
PA15.GPIO_Label=SDCARD
PA15.Signal=GPIO_Input
PA5.Signal=SPI1_SCK
PA7.Signal=SPI1_MOSI
PA8.GPIO_Label=BUZZER_PWM
PA8.Signal=S_TIM1_CH1
PA9.GPIO_Label=GPS_USART_TX
PA9.Signal=USART1_TX
PB0.GPIO_Label=SX_RST
PB0.Signal=GPIO_Output
PB1.GPIO_Label=BTN_NEXT
PB1.Signal=GPXTI1
PB10.GPIO_Label=BT_USART_TX
PB10.Signal=USART3_TX
PB11.GPIO_Label=BT_USART_RX
PB11.Signal=USART3_RX
PB13.Signal=SPI2_SCK
PB14.GPIO_Label=SPI_CS
PB14.Signal=GPIO_Output
PB15.GPIO_Label=RST
PB15.Signal=GPIO_Output
PB2.GPIO_Label=BTN_OK
PB2.Signal=GPXTI2
PB4.GPIO_Label=BTN_CANCEL
PB4.Signal=GPXTI4
PB5.GPIO_Label=BTN_PREV
PB5.Signal=GPXTI5
PB7.Signal=I2C1_SDA
PB8.Signal=I2C1_SCL
PB9.GPIO_Label=LED
PB9.Signal=GPIO_Output
PC1.GPIO_Label=PWR_EN
PC1.Signal=GPIO_Output
PC10.Signal=SDIO_D2
PC11.Signal=SDIO_D3
PC12.Signal=SDIO_CK
PC14-OSC32_IN.Signal=RCC_OSC32_IN
PC15-OSC32_OUT.Signal=RCC_OSC32_OUT
PC2.Signal=SPI2_MISO
PC3.Signal=SPI2_MOSI
PC4.GPIO_Label=SX_NSS
PC4.Signal=GPIO_Output
PC5.GPIO_Label=SX_INT
PC5.Signal=GPIO_Input
PC6.GPIO_Label=BUSY
PC6.Signal=GPIO_Input
PC7.GPIO_Label=DC
PC7.Signal=GPIO_Output
PC8.Signal=SDIO_D0
PC9.Signal=SDIO_D1
PD2.Signal=SDIO_CMD
PH0-OSC_IN.Signal=RCC_OSC_IN
PH1-OSC_OUT.Signal=RCC_OSC_OUT

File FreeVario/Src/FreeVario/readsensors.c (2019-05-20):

/*
 FreeVario http://FreeVario.org

 Copyright (c), FreeVario (http://freevario.org)
 This program is free software: you can redistribute it and/or modify
 it under the terms of the GNU General Public License as published by
 the Free Software Foundation, either version 3 of the License, or
 any later version. see <http://www.gnu.org/licenses/>
 */

#include "readsensors.h"
#include "kalman.h"
#include "MadgwickAHRS.h"
#include "freevario.h"

extern I2C_HandleTypeDef FV_I2C;
extern ADC_HandleTypeDef FV_HALADC;


#define MPU6050_ACCE_SENS_2         ((float) 16384)
#define MPU6050_ACCE_SENS_4         ((float) 8192)
#define MPU6050_ACCE_SENS_8         ((float) 4096)
#define MPU6050_ACCE_SENS_16        ((float) 2048)

#define QUAT_W 0
#define QUAT_X 1
#define QUAT_Y 2
#define QUAT_Z 3

#define VEC_X 0
#define VEC_Y 1
#define VEC_Z 2

char _orientation[9] = { 0, -1, 0, 1, 0, 0, 0, 0, -1 };

static uint8_t vTriggerd;
static uint32_t vtime = 0;

void setupVbatSensor() {
    HAL_ADC_Start(&FV_HALADC);
    sensors.vbat = 30;
    sensors.pbat = 100;

}

void readVbatSensor() {

    if (HAL_ADC_PollForConversion(&FV_HALADC, 100) == HAL_OK) {

        uint32_t cnv = HAL_ADC_GetValue(&FV_HALADC);

        /*TODO: in dire need of calibration, use your scope man*/
        sensors.vbat = (sensors.vbat * 10 + (float)((cnv * 2 * 62) / 0xfff) )
                / 11; //lowpassfilter

        //calculate %charge, sort of
        sensors.pbat = (uint8_t) ((37 - sensors.vbat) * 16.6);

        if (sensors.pbat > 100) {
            sensors.pbat = 100;
        }

    }

}

void setupReadSensorsBMP280(BMP280_HandleTypedef *bmp280) {
    //TODO: Replace with official drivers
    //https://github.com/BoschSensortec/BME280_driver

    bmp280_init_default_params(&bmp280->params);
    bmp280->addr = BMP280_I2C_ADDRESS_0;
    bmp280->i2c = &FV_I2C;

    bmp280->params.mode = BMP280_MODE_NORMAL;
    bmp280->params.filter = BMP280_FILTER_2;
    bmp280->params.oversampling_pressure = BMP280_ULTRA_HIGH_RES;
    bmp280->params.oversampling_temperature = BMP280_LOW_POWER;
    bmp280->params.oversampling_humidity = BMP280_ULTRA_LOW_POWER;
    bmp280->params.standby = BMP280_STANDBY_05;

    while (!bmp280_init(bmp280, &bmp280->params)) {
    }

    SO_setQueue(&sensors.QAltitudeMeters, 10); //vario m/s

}

void setupReadSensorsMPU6050(SD_MPU6050 *mpu1) {
    SD_MPU6050_Init(&FV_I2C, mpu1, FV_ACCL_ADR, SD_MPU6050_Accelerometer_4G,
            SD_MPU6050_Gyroscope_250s);

    SD_MPU6050_SetOrientation(&FV_I2C, mpu1, Matrix2Scalar(_orientation));
}

void setupKalman() {

    KalmanFilter_Configure(Z_VARIANCE, ZACCEL_VARIANCE, ZACCELBIAS_VARIANCE, 0,
            0.0f, 0.0f);

}

//not yet used, needs work
void calcSensorsKalman(BMP280_HandleTypedef *bmp280, SD_MPU6050 *mpu1) {
    float zTrack, vTrack;

    sensors.accel_x = mpu1->Accelerometer_X * 100 / MPU6050_ACCE_SENS_4;
    sensors.accel_y = 0; //mpu1->Accelerometer_Y*100/MPU6050_ACCE_SENS_4;
    sensors.accel_z = (mpu1->Accelerometer_Z * 100 / MPU6050_ACCE_SENS_4) - 98; //upside down

    sensors.gyro_x = (ACCLSMOOTH * sensors.gyro_x + mpu1->Gyroscope_X)
            / (ACCLSMOOTH + 1);
    sensors.gyro_y = (ACCLSMOOTH * sensors.gyro_y + mpu1->Gyroscope_Y)
            / (ACCLSMOOTH + 1);
    sensors.gyro_z = (ACCLSMOOTH * sensors.gyro_z + mpu1->Gyroscope_Z)
            / (ACCLSMOOTH + 1);

    // MadgwickAHRSupdateIMU(sensors.gyro_x,sensors.gyro_y, sensors.gyro_z,sensors.accel_x,sensors.accel_y, sensors.accel_z);

    //float accelv = (9.8f*imu_GravityCompensatedAccel(sensors.accel_x,sensors.accel_y, sensors.accel_z));

    float accelv = 9.8f
            * sqrtf(powf(sensors.accel_x, 2) + powf(sensors.accel_z, 2)); //just the z and x axes

    sensors.gforce = accelv / 100;

    if (activity.useKalman) {
        KalmanFilter_Update((float) sensors.VarioMsRaw / 10, accelv / 100,
                (float) SENSORREADMS / 1000, &zTrack, &vTrack); // values must be cm/s
        sensors.VarioMs = vTrack * 10; //from cm/s to mm/s
    } else {
        sensors.VarioMs = sensors.VarioMsRaw;
    }

}

void readSensorsBMP280(BMP280_HandleTypedef *bmp280) {

    uint32_t pressure;
    int16_t temperature, humidity;

    while (!bmp280_read_int(bmp280, &temperature, &pressure, &humidity)) {

    }

    sensors.humidity = humidity;
    sensors.temperature = temperature;
    sensors.pressureraw = pressure;

    if (activity.useKalman) {
        sensors.pressure = pressure;
    } else {
        sensors.pressure = (sensors.variosmooth * sensors.pressure + pressure)
                / (sensors.variosmooth + 1);

    }

}

void readSensorsMPU6050(SD_MPU6050 *mpu1) {

    SD_MPU6050_ReadAll(&FV_I2C, mpu1);

}

float getAltitudeFeet() { //x1000

    return getAltitudeMeters() * 145366.45;

}

float getAltitudeMeters() {

    return 44330.0f
            * (1.0f
                    - powf(
                            ((float) sensors.pressure / 100)
                                    / (float) conf.qnePressure, 0.1902949f)); //because Pressure is in Pa x 100

}

//This must be called every 50ms (value x2)
void calculateVario50ms() {

    float alt = getAltitudeMeters();
    sensors.AltitudeMeters = (int32_t) (alt * 1000);
    SO_enqueue(&sensors.QAltitudeMeters, alt);

    if (SO_qisFull(&sensors.QAltitudeMeters)) {
        //called per 50ms, so value *2
        sensors.VarioMsRaw = (int32_t) ((SO_rear(&sensors.QAltitudeMeters)
                - SO_front(&sensors.QAltitudeMeters)) * 1000) * 2;

    } else {
        sensors.VarioMsRaw = 0;
        sensors.VarioMs = 0;
    }

}

unsigned short Row2Scale(const char *row) {
    unsigned short b;

    if (row[0] > 0)
        b = 0;
    else if (row[0] < 0)
        b = 4;
    else if (row[1] > 0)
        b = 1;
    else if (row[1] < 0)
        b = 5;
    else if (row[2] > 0)
        b = 2;
    else if (row[2] < 0)
        b = 6;
    else
        b = 7;

    return b;
}

unsigned short Matrix2Scalar(const char *mtx) {
    unsigned short scalar;

    scalar = Row2Scale(mtx);
    scalar |= Row2Scale(mtx + 3) << 3;
    scalar |= Row2Scale(mtx + 6) << 6;

    return scalar;
}
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

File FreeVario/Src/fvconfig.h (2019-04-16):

/*
 FreeVario http://FreeVario.org

  Copyright (c), FreeVario (http://freevario.org)
  This program is free software: you can redistribute it and/or modify
  it under the terms of the GNU General Public License as published by
  the Free Software Foundation, either version 3 of the License, or
  any later version. see <http://www.gnu.org/licenses/>
*/


#ifndef FVCONFIG_H_
#define FVCONFIG_H_
#ifdef __cplusplus
 extern "C" {
#endif
#include "math.h"
#include "stdbool.h"

#include "fvconfig_hal.h"
#include "settings.h"
#include "stackops.h"



//#define SETUPBT
#ifdef DEBUG_MODE
#define DEBUGUSBOUT //use the usb for print. It disable sending data out
#endif

#define ACCLSMOOTH 10 //Lowpass filter level
#define UPDATELOGFILETIME 30000 //time in ms to update de Log summary file
#define LANDEDSPEED 5 //Ground Speed in knots to detect landing
#define TAKEOFFSPEED 10 //Ground Speed in knots to detect takeoff
#define LANDEDLOWSPEEDTIME 20000 //Time in ms groundspeed lower than LANDEDSPEED to trigger landed detection
#define STARTDELAY 8000 //the time delay before the process starts
#define TAKEOFFVARIO 800 //0.4 //abs vario level to detect takeoff
#define BUZZERZEROCLIMB -0.2 // Normal sink rate for glider is -0.9 m/s. At this value up to 0 m/s a "blip" sound is made
//#define BUZZERSTARTUPSOUND // beep when starting up
#define BUZZER //enble the buzzer function
#define BUZZSINKALERT -2 //Alert if sinking harder than normal (not sink alarm)
#define BUZZSINKALERTPAUSE 8000 //pause length in between alerts
#define BUZZERVARIOSTOP 10000 //time vario STOP making noise when climbrate 0 m/s
//#define OUTOFTHERMALBUZZT 3000 //time buzzer goes buuhhhhh
#define SOARDETECTION 30000 // if climbrate is constant for set milliseconds at 0 m/s the buzzer is muted
#define BUZZERCLIMBING 0.1 // vario level to start giving climbing signal
#define AUDIOSMOOTH 10 //smooth out audio changes
#define ADAPTIVEVARIO //Adapts the vario low pass filter

#define SENSORREADMS    50  //ms sensors are read
//#define TESTBUZZER

#define SENDBUFFER 164 //global size of the send buffer
#define GPSRXBUFFER 1024
#define CONFIGFILENAME "settings.cfg"

#define PWRBUTTONDELAY 3000//Time powerbutton must be pressed


 // Z_VARIANCE is the measured sensor altitude cm noise variance, with sensor at rest, normal sampling rate, and 1-2 seconds max samples
 // I personally use a somewhat smaller value than the measured variance as I favour a faster response to step inputs and am willing to
 // tolerate a bit of jitter with the unit at rest.
 #define Z_VARIANCE          800.0f

 // The filter models acceleration as an external environmental disturbance to the system, ZACCEL_VARIANCE is the estimated
 // variance of the perturbations. For a paragliding application, this would be the expected acceleration variance due to thermal
 // activity, how sharp the thermal edges are, etc.  This is NOT the accelerometer sensor noise variance. Increase this value and the
 // filter will respond faster to acceleration inputs.
 #define ZACCEL_VARIANCE     100.0f

 // The accelerometer bias (offset between true acceleration and measured value) is not likely to change rapidly, so a low value
 // of ZACCELBIAS_VARIANCE will enforce that. But too low a value, and the filter will take longer on reset to settle to the estimated
 // value. For an audio variometer, the symptom would be the variometer beeping for several seconds after reset, with the unit at rest.
 #define ZACCELBIAS_VARIANCE 1.0f


#endif /* FVCONFIG_H_ */

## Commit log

2019-02-09 Added takeoff and landing timestamps from RTC
2019-03-07 Changes to adapt the new board
2019-04-04 Added button control display refresh and some bug fixes
    [FreeVario.ioc, freevario.c, fvconfig.h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]
2019-04-04 Switch from RTC to GPS timer. STM32 RTC HAL is not very functional.
2019-04-05 Replaced and added new fonts.
    [FreeVario.ioc, main.c, readsensors.c]
2019-04-07 Added mute function, fixed BT race condition
    [freevario.c, fvconfig.h, fvconfig_hal.h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]
2019-04-08 Changed pressure sensor sample rate to 100ms
2019-04-09 Fixed mute function, added GNSS calibration to baro altitude
    [freevario.c, main.c, readsensors.c]
2019-04-10 Removed LED flashing
2019-04-11 Started testing with a kalman filter.
2019-04-12 Added more adaptions to the filter
2019-04-14 Added adaptive vario and optional kelman filter for testing
2019-04-14 Reactivated power delay switch
2019-04-15 Replaced sqrt with sqrtf. Improved audio
    [audio.c, freevario.c, fvconfig.h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]
2019-04-15 Corrected battery voltage reading
    [readsensors.c]
2019-04-16 Updated GPS lib. Switched double to float for the FPU usage
2019-04-18 Lower sample rate for humidity
2019-04-18 Testing the PWM options
2019-05-12 Added support for 1.2 board verions
2019-05-20 Changed adaptive vario to use sensor struct. Added extra sdcard mount
2019-05-20 Fixed startup wild values
    [FreeVario.ioc, main.c]
2019-05-20 Lowerd the e-ink spi speed to 7.5 MB/s
2019-05-30 Completed gpx track format
2019-09-14 Added Case and Pcb design
    [FreeVario F4 V1.2.1.ods, FreeVario F4 V1.2.brd, FreeVario F4 V1.2.csv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]

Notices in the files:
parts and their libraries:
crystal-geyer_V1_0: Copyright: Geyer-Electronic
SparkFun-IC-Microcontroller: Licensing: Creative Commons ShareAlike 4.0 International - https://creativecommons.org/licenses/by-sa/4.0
